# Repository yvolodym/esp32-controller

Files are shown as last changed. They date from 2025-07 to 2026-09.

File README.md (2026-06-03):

## Controller

ESP32-WROVER based wireless game controller. Two resistive (potentiometer)
analog joysticks plus an ST7789 SPI display, transmitting over ESP-NOW.
Firmware uses native ESP-IDF — see `CLAUDE.md` for architecture and pin
layout details.

### References

#### ESP-NOW
* https://randomnerdtutorials.com/esp32-cyd-esp-now-receive-data/
* https://habr.com/ru/companies/beget/articles/929336/
* https://wolles-elektronikkiste.de/esp-now
* https://github.com/SolderedElectronics/USB-UART-CH340C-converter-board-hardware-design

#### Joysticks (resistive thumbstick modules)
* https://tech.alpsalpine.com/e/products/detail/RKJXV122400R/
* https://github.com/dbenoy/thumbstick-breakout/blob/main/docs/board.png

#### LiPo charging module
* https://elektro.turanis.de/html/prj224/index.html

### Pin assignments

`CLAUDE.md` is the source of truth — the lists below are a quick reference.
All pins verified against `kicad/esp32-controller.kicad_sch` and
`kicad/supply.kicad_sch`.

#### ST7789 display (J1, 8-pin header — VSPI)

| J1 pin | Signal | GPIO |
|---|---|---|
| 1 | BL (backlight) | GPIO15 |
| 2 | CS  | GPIO5  |
| 3 | DC  | GPIO2  |
| 4 | RST | GPIO4  |
| 5 | MOSI / SDA | GPIO23 |
| 6 | SCK / SCL  | GPIO18 |
| 7 | VCC | +3.3 V |
| 8 | GND | GND |

#### Joystick 1 — RIGHT stick (U2 in schematic)

| Signal | GPIO | ADC |
|---|---|---|
| VRx (X axis) | GPIO32 | ADC1_CH4 |
| VRy (Y axis) | GPIO33 | ADC1_CH5 |
| Button (SEL) | GPIO25 | — *(not wired in hardware, see CLAUDE.md)* |

#### Joystick 2 — LEFT stick (U3 in schematic)

| Signal | GPIO | ADC |
|---|---|---|
| HRx (X axis) | GPIO34 | ADC1_CH6 |
| HRy (Y axis) | GPIO35 | ADC1_CH7 |
| Button (SEL) | GPIO26 | — *(not wired in hardware, see CLAUDE.md)* |

#### Battery sense

| Signal | GPIO | ADC |
|---|---|---|
| VBAT divider (R17 220 kΩ / R18 100 kΩ, net `HVBAT`) | GPIO36 (SENSOR_VP) | ADC1_CH0 |

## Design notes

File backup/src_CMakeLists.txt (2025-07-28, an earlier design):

idf_component_register(SRCS "main.cpp"
                    PRIV_INCLUDE_DIRS .
                    PRIV_REQUIRES nvs_flash
                    REQUIRES "fatfs" "esp_event" "esp_timer" "driver")
target_compile_definitions(${COMPONENT_LIB} PUBLIC "-DLOG_LOCAL_LEVEL=ESP_LOG_VERBOSE")

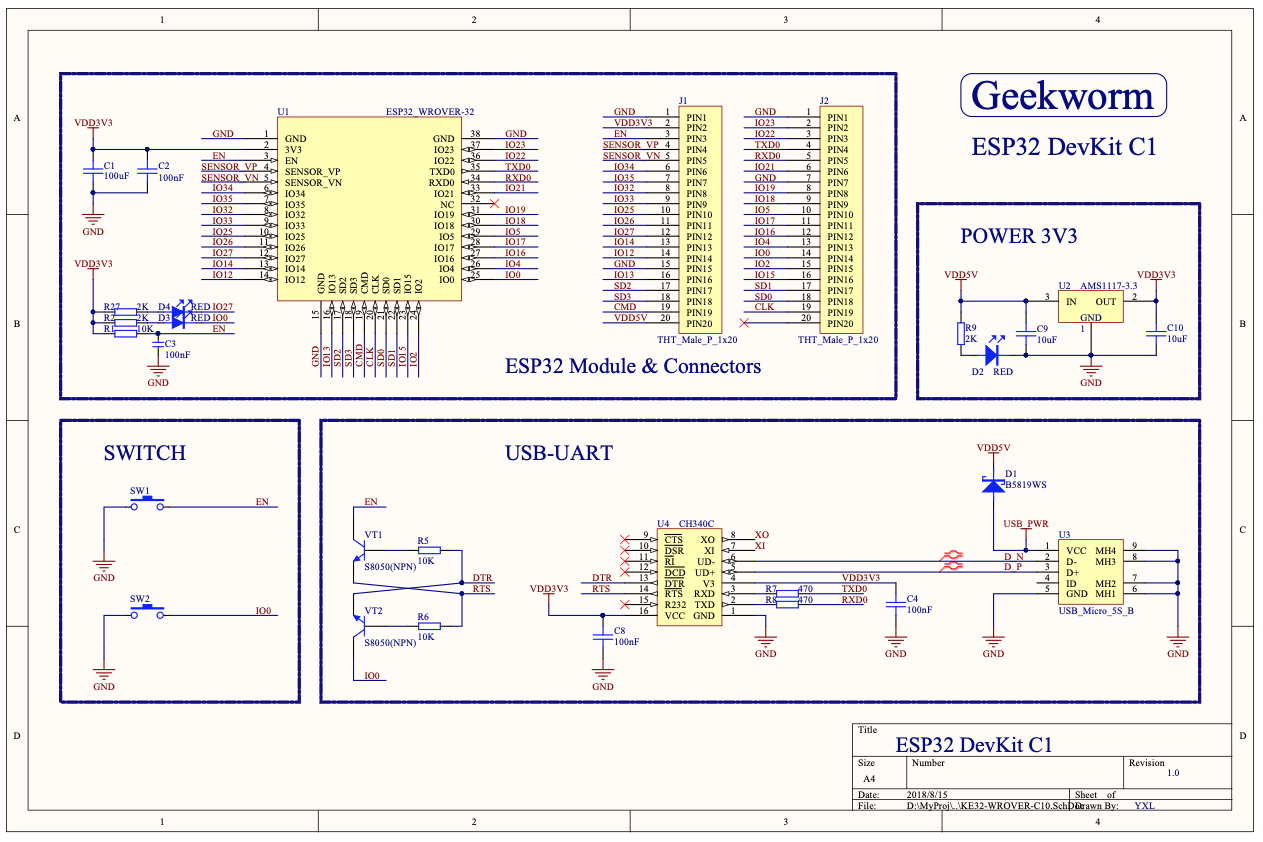
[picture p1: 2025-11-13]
doc/scematic.png

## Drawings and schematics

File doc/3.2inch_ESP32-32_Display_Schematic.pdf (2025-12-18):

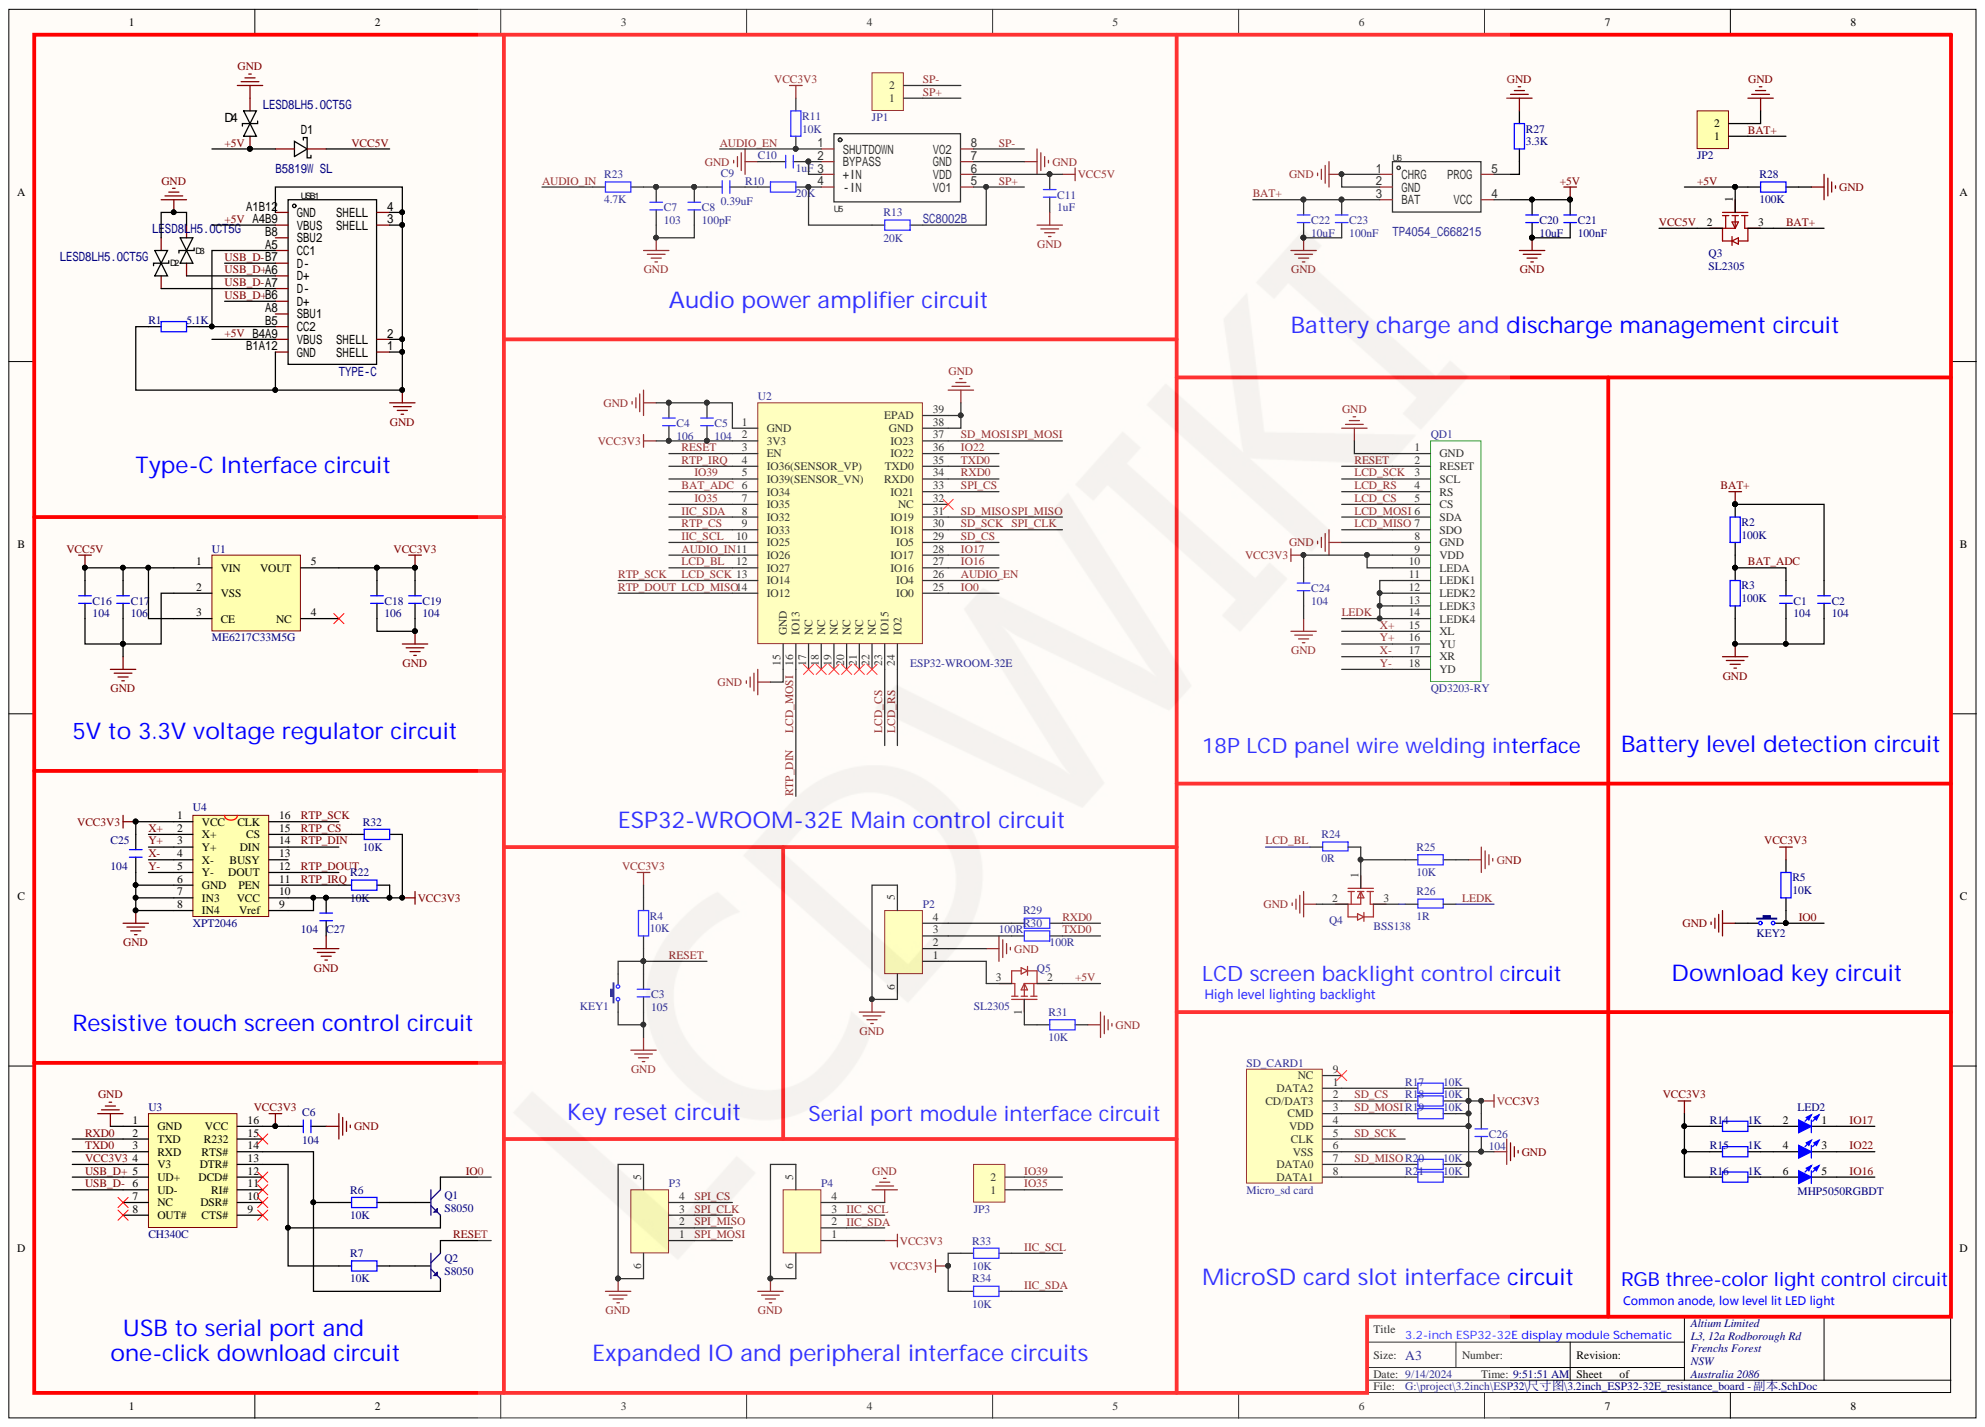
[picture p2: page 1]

GND
Audio power amplifier circuit

Battery charge and discharge management circuit

GND | BAT+

5V to 3.3V voltage regulator circuit

ESP32-WROOM-32E Main control circuit

High level lighting backlight

Resistive touch screen control circuit

R19 | | 10K | VCC3V3 SD_MOSI

VCC3V3 MHP5050RGBDT

Common anode, low level lit LED light

USB to serial port and
one-click download circuit

Expanded IO and peripheral interface circuits

Title 3.2-inch ESP32-32E display module Schematic | Altium Limited L3, 12a Rodborough Rd Frenchs Forest NSW Australia 2086

Size: A3 | Number: | Revision:

Date: 9/14/2024 Time: 9:51:51 AM | | Sheet of

G:\project\3.2inch\ESP32\尺寸图\3.2inch_ESP32-32E_resistance_board - 副本.SchDoc

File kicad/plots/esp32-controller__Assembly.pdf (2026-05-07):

1 | 2 | 3 | 4 | 5 | 6

A

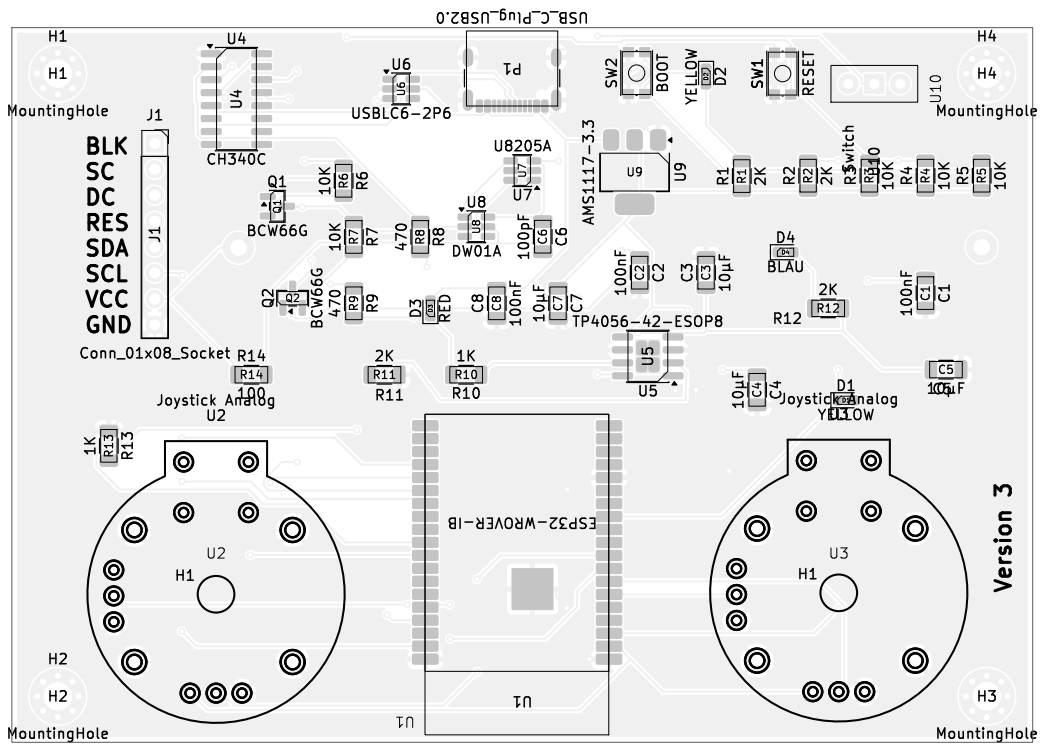
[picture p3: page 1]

1 | 2 | 3 | 4 | 5 | 6

A

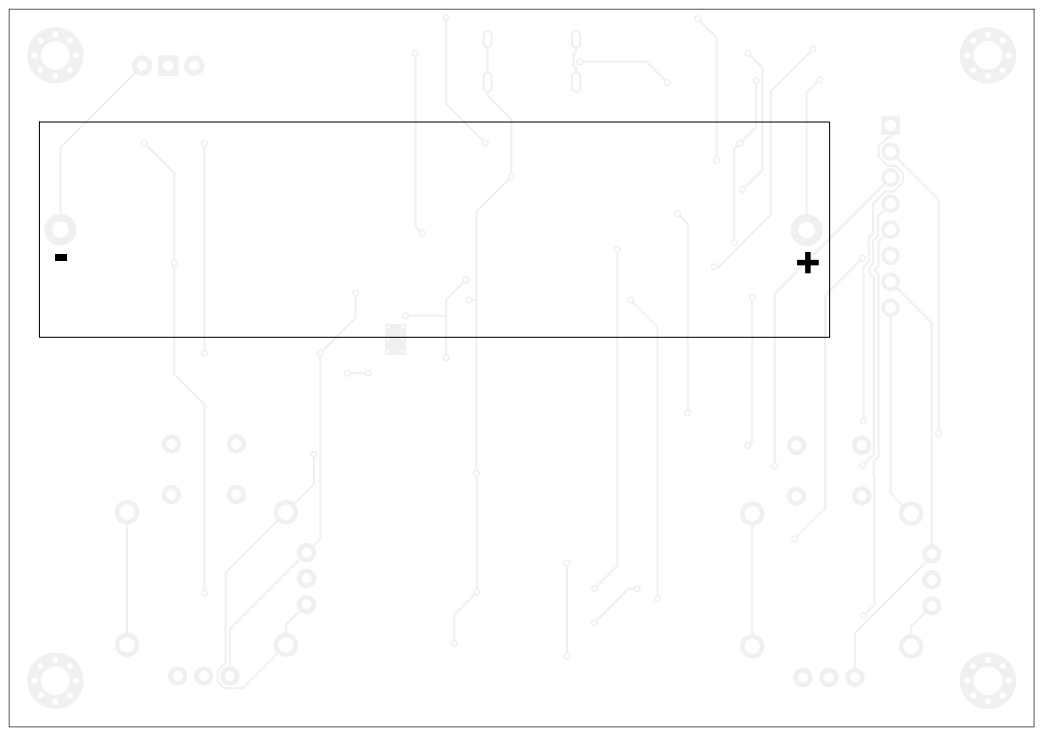
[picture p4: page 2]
D Date: KiCad; E.D.A. 9.0.8 Size: A4; Rev:; Id: /1 Title: File: esp32-controller.kicad_pcb Sheet: Black; And; White; BOT Board2Pdf:; Black; BOT -; Page 2/2

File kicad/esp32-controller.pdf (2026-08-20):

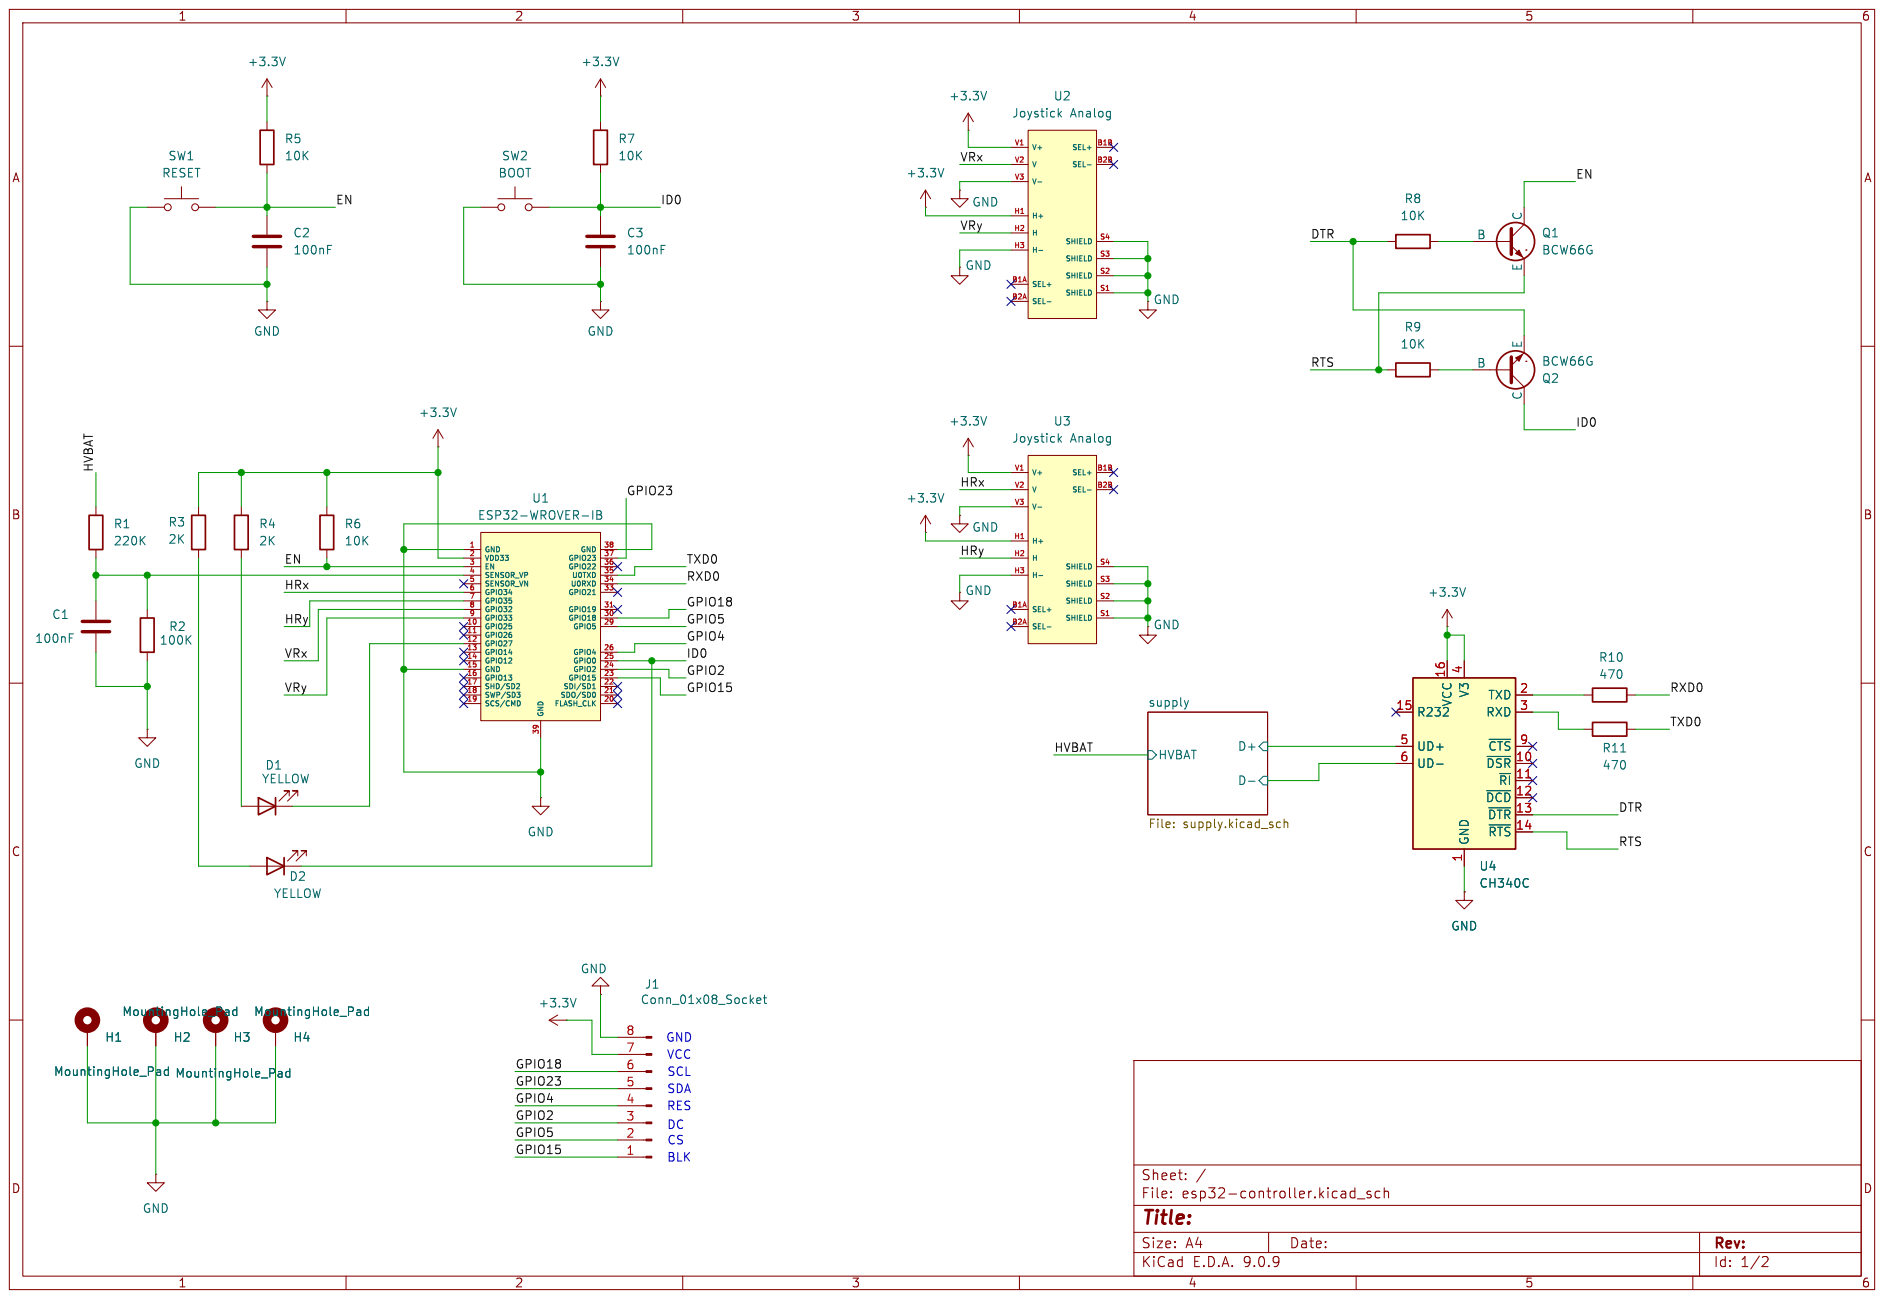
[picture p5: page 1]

VRy VRx HRx EN

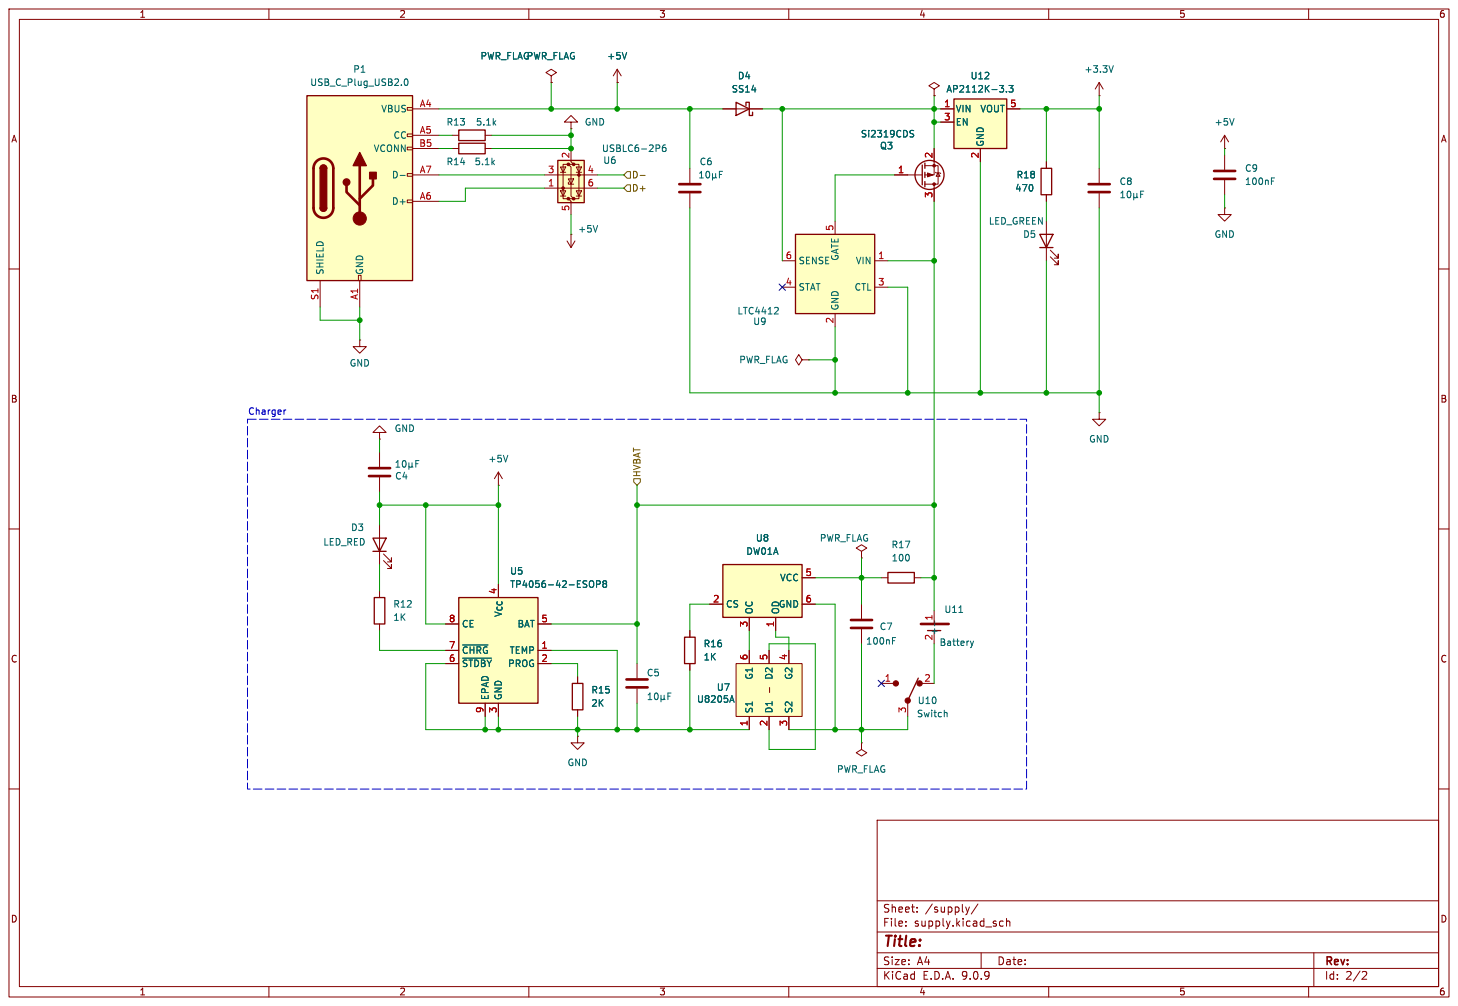
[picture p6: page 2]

3 CS 2 U5 TP4056-42-ESOP8 CE 8 ~{CHRG} 7 ~{STDBY} 6 EPAD

Id: 2/2 Title: File: supply.kicad_sch Sheet: /supply/ C5

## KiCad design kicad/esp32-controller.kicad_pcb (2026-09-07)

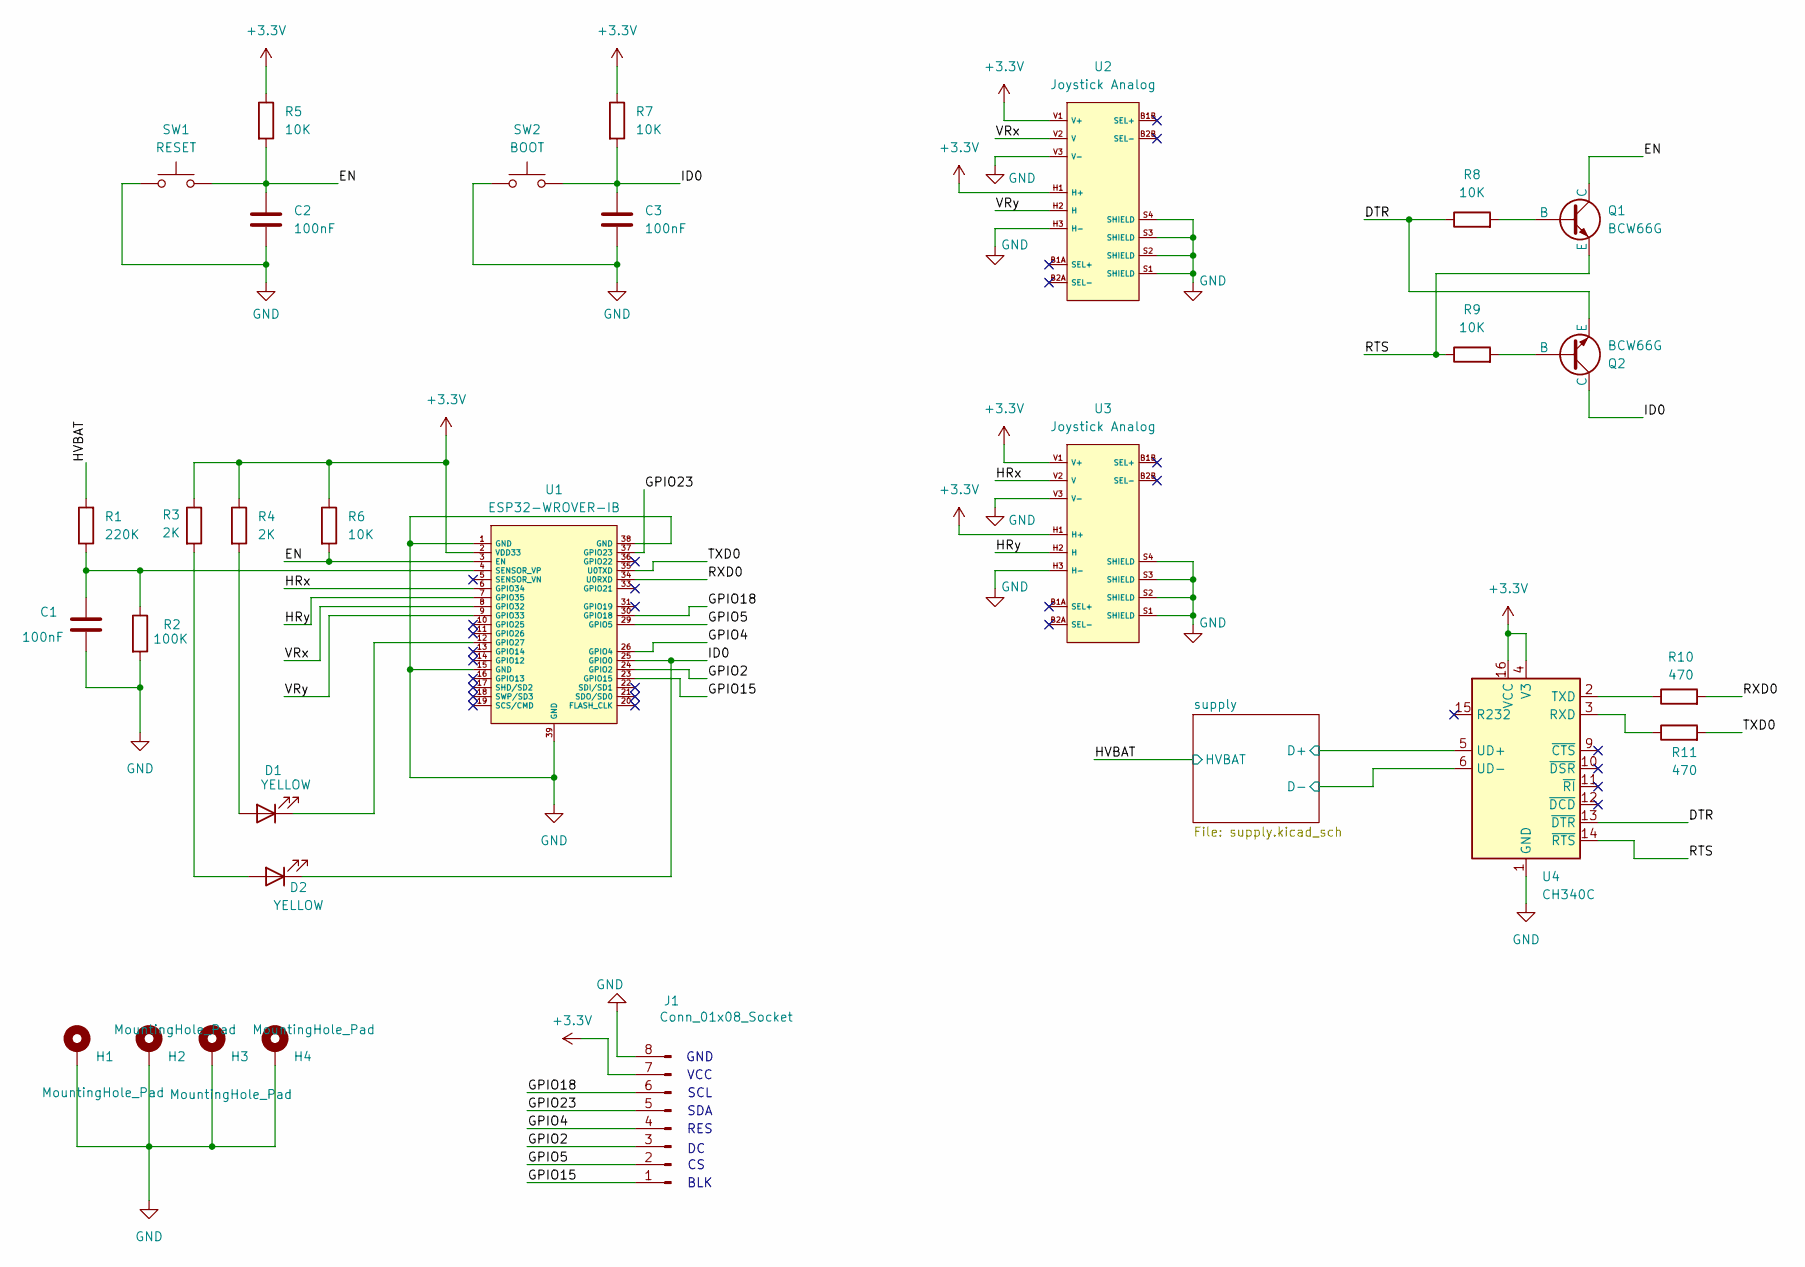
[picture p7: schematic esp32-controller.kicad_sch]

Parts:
C1, C2, C3: 100nF; C_1206_3216Metric
D1, D2: YELLOW; D_0603_1608Metric
H1, H2, H3, H4: MountingHole_Pad; MountingHole_2.7mm_Pad_Via
J1: Conn_01x08_Socket; PinSocket_1x08_P2.54mm_Vertical
Q1, Q2: BCW66G; SOT-23
R1: 220K; R_1206_3216Metric
R2: 100K; R_1206_3216Metric
R3, R4: 2K; R_1206_3216Metric
R5, R6, R7: 10K; R_1206_3216Metric
R8, R9: 10K; R_1206_3216Metric; LCSC C25819
R10, R11: 470; R_1206_3216Metric; LCSC C25819
SW1: RESET; SW_PUSH_1P1T_6x3.5mm_H4.3_APEM_MJTP1243
SW2: BOOT; SW_PUSH_1P1T_6x3.5mm_H4.3_APEM_MJTP1243
U1: ESP32-WROVER-IB
U2, U3: Joystick Analog; Joystick_Analog
U4: CH340C; SOIC-16_3.9x9.9mm_P1.27mm

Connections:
+3.3V: J1.7, R3.1, R4.1, R5.1, R6.1, R7.1, U1.2 (VDD33), U2.H1 (H+), U2.V1 (V+), U3.H1 (H+), U3.V1 (V+), U4.4 (V3), U4.16 (VCC); also elsewhere on the board
/DTR: Q2.3 (E), R8.1, U4.13 (~DTR)
/EN: C2.1, Q1.1 (C), R5.2, R6.2, SW1.2, U1.3 (EN)
/GPIO2: J1.3, U1.24 (GPIO2)
/GPIO4: J1.4, U1.26 (GPIO4)
/GPIO5: J1.2, U1.29 (GPIO5)
/GPIO15: J1.1, U1.23 (GPIO15)
/GPIO18: J1.6, U1.30 (GPIO18)
/GPIO23: J1.5, U1.37 (GPIO23)
/HRx: U1.6 (GPIO34), U3.V2 (V)
/HRy: U1.7 (GPIO35), U3.H2 (H)
/HVBAT: R1.2; also elsewhere on the board
/ID0: C3.1, D2.1 (K), Q2.1 (C), R7.2, SW2.2, U1.25 (GPIO0)
/RTS: Q1.3 (E), R9.1, U4.14 (~RTS)
/RXD0: R10.2, U1.34 (U0RXD)
/TXD0: R11.2, U1.35 (U0TXD)
/VRx: U1.8 (GPIO32), U2.V2 (V)
/VRy: U1.9 (GPIO33), U2.H2 (H)
/supply/D+: U4.5 (UD+); also elsewhere on the board
/supply/D-: U4.6 (UD-); also elsewhere on the board
GND: C1.2, C2.2, C3.2, H1.1, H2.1, H3.1, H4.1, J1.8, R2.2, SW1.1, SW2.1, U1.1 (GND), U1.15 (GND), U1.38 (GND), U1.39 (GND), U2.H3 (H-), U2.S1 (SHIELD), U2.S2 (SHIELD), U2.S3 (SHIELD), U2.S4 (SHIELD), U2.V3 (V-), U3.H3 (H-), U3.S1 (SHIELD), U3.S2 (SHIELD), U3.S3 (SHIELD), U3.S4 (SHIELD), U3.V3 (V-), U4.1 (GND); also elsewhere on the board
unnamed: D1.2 (A), R4.2
unnamed: D1.1 (K), U1.12 (GPIO27)
unnamed: D2.2 (A), R3.2
unnamed: Q1.2 (B), R8.2
unnamed: Q2.2 (B), R9.2
unnamed: C1.1, R1.1, R2.1, U1.4 (SENSOR_VP)
unnamed: R11.1, U4.3 (RXD)
unnamed: R10.1, U4.2 (TXD)

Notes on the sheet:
RES
VCC
SCL
GND
BLK
SDA

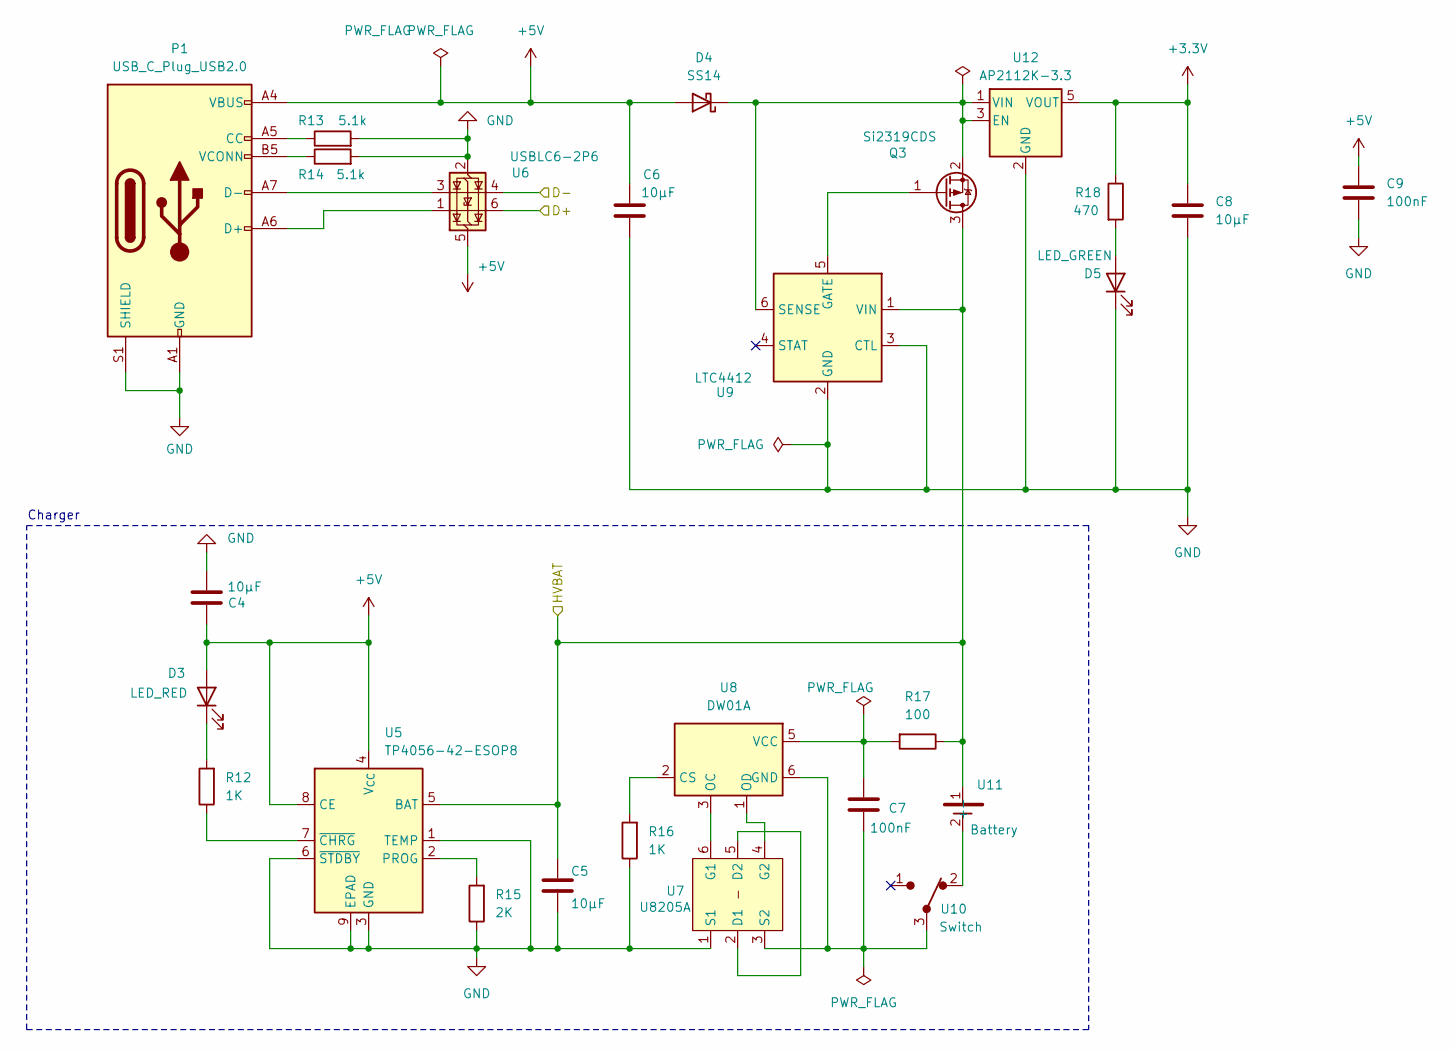
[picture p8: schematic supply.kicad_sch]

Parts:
C4, C5, C6, C8: 10µF; C_1206_3216Metric
C7, C9: 100nF; C_1206_3216Metric
D3: LED_RED; LED_D2.0mm_W4.8mm_H2.5mm_FlatTop
D4: SS14; D_SMA
D5: LED_GREEN; LED_D2.0mm_W4.8mm_H2.5mm_FlatTop
P1: USB_C_Plug_USB2.0; USB_C_Receptacle_GCT_USB4105-xx-A_16P_TopMnt_Horizontal; LCSC C456012
Q3: Si2319CDS; SOT-23
R12, R16: 1K; R_1206_3216Metric
R13, R14: 5.1k; R_1206_3216Metric
R15: 2K; R_1206_3216Metric
R17: 100; R_1206_3216Metric
R18: 470; R_1206_3216Metric
U5: TP4056-42-ESOP8; SOIC-8-1EP_3.9x4.9mm_P1.27mm_EP2.41x3.3mm_ThermalVias
U6: USBLC6-2P6; SOT-23-6
U7: U8205A; SOT-23-6
U8: DW01A; SOT-23-6
U9: LTC4412; TSOT-23-6
U10: Switch; SW_SPDT_PCM12
U11: Battery; NCR18650B
U12: AP2112K-3.3; SOT-23-5

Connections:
+3.3V: C8.1, R18.1, U12.5 (VOUT); also elsewhere on the board
+5V: C4.1, C6.1, C9.2, D3.2 (A), D4.2 (A), P1.A4 (VBUS), P1.A9 (VBUS), P1.B4 (VBUS), P1.B9 (VBUS), U5.4 (V_{CC}), U5.8 (CE), U6.5 (VBUS)
/HVBAT: C5.1, Q3.3 (D), R17.1, U5.5 (BAT), U9.1 (VIN), U11.1 (+); also elsewhere on the board
/supply/D+: U6.6 (I/O1); also elsewhere on the board
/supply/D-: U6.4 (I/O2); also elsewhere on the board
GND: C4.2, C5.2, C6.2, C8.2, C9.1, D5.1 (K), P1.A1 (GND), P1.A12 (GND), P1.B1 (GND), P1.B12 (GND), P1.S1 (SHIELD), R13.2, R14.2, R15.1, R16.1, U5.1 (TEMP), U5.3 (GND), U5.6 (~STDBY), U5.9 (EPAD), U6.2 (GND), U7.1 (S1), U9.2 (GND), U9.3 (CTL), U12.2 (GND); also elsewhere on the board
unnamed: D3.1 (K), R12.2
unnamed: D4.1 (K), Q3.2 (S), U9.6 (SENSE), U12.1 (VIN), U12.3 (EN)
unnamed: D5.2 (A), R18.2
unnamed: P1.A5 (CC), R13.1
unnamed: P1.A6 (D+), U6.1 (I/O1)
unnamed: P1.A7 (D-), U6.3 (I/O2)
unnamed: P1.B5 (VCONN), R14.1
unnamed: Q3.1 (G), U9.5 (GATE)
unnamed: R15.2, U5.2 (PROG)
unnamed: R12.1, U5.7 (~CHRG)
unnamed: U7.2 (D1), U7.5 (D2)
unnamed: U7.6 (G1), U8.3 (OC)
unnamed: U7.4 (G2), U8.1 (OD)
unnamed: C7.1, U7.3 (S2), U8.6 (GND), U10.3
unnamed: R16.2, U8.2 (CS)
unnamed: C7.2, R17.2, U8.5 (VCC)
unnamed: U10.2, U11.2 (-)

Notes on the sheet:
Charger

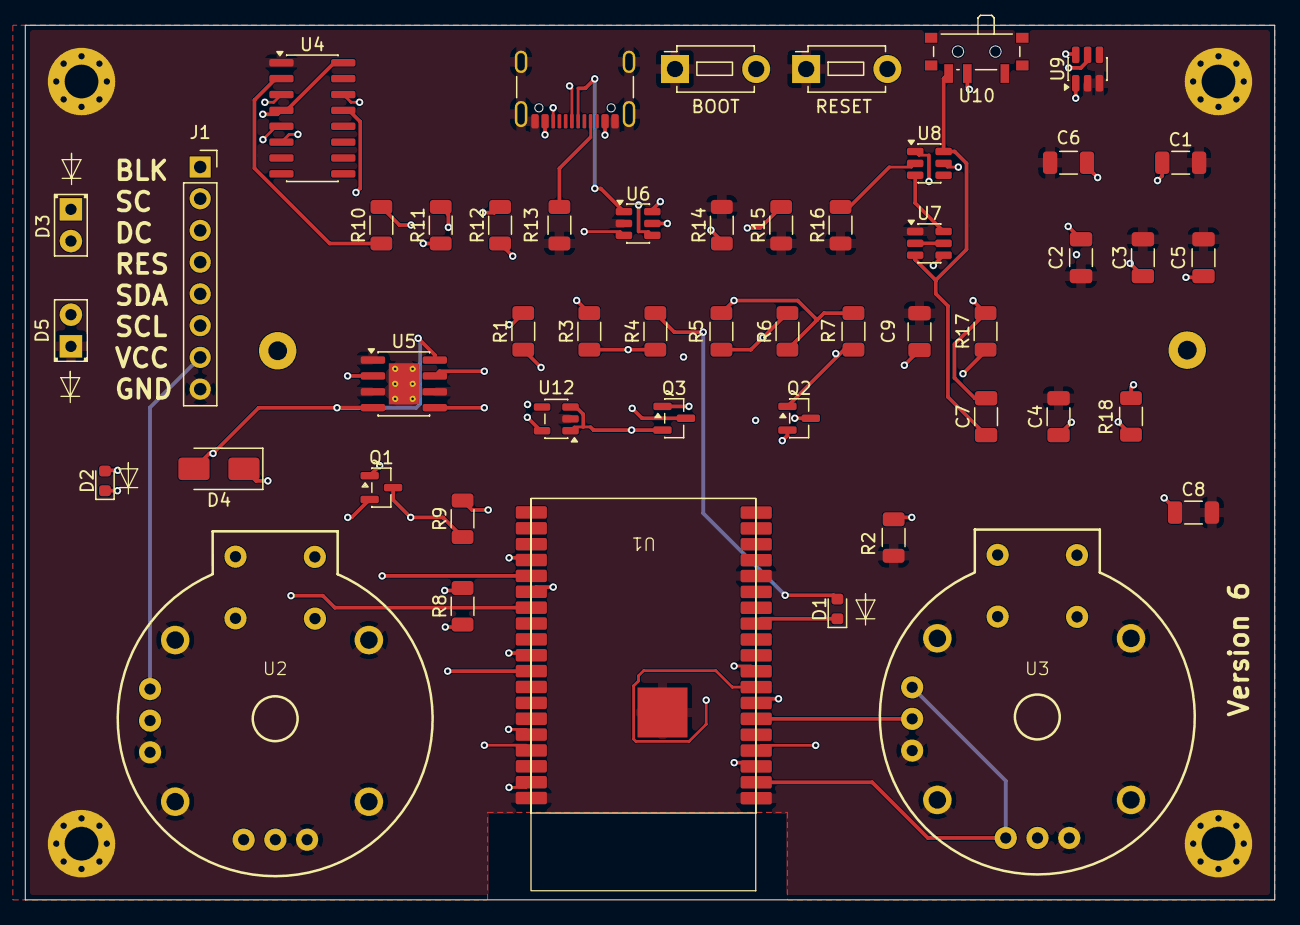
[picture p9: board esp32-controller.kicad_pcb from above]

Board: 4 copper layers, 100.0 x 70.0 mm, 55 parts (1 on the bottom side), 47 nets.

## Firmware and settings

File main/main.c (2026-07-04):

#include <stdio.h>
#include <string.h>
#include <stdlib.h>
#include <freertos/FreeRTOS.h>
#include <freertos/task.h>
#include <esp_system.h>
#include <esp_wifi.h>
#include <esp_now.h>
#include <esp_log.h>
#include <esp_adc/adc_oneshot.h>
#include <esp_adc/adc_cali.h>
#include <esp_adc/adc_cali_scheme.h>
#include <driver/gpio.h>
#include <nvs_flash.h>
#include <sdkconfig.h>
#include "st7789_display.h"

static const char *TAG = "ESP32_CONTROLLER";

// ========== CONFIGURATION ========== //
// Joystick 1 (U2 in schematic, net /VRx /VRy)
#define JOY1_X_PIN ADC_CHANNEL_4  // GPIO32 - X-axis joystick 1
#define JOY1_Y_PIN ADC_CHANNEL_5  // GPIO33 - Y-axis joystick 1
// Joystick 2 (U3 in schematic, net /HRx /HRy)
#define JOY2_X_PIN ADC_CHANNEL_6  // GPIO34 - X-axis joystick 2
#define JOY2_Y_PIN ADC_CHANNEL_7  // GPIO35 - Y-axis joystick 2
// Joystick buttons
#define JOY1_BTN_PIN GPIO_NUM_25  // Joystick 1 button
#define JOY2_BTN_PIN GPIO_NUM_26  // Joystick 2 button

// Battery voltage sense — VBAT through a 220k/100k divider into GPIO36.
// HW prerequisite: R17/R18/C9 (net VBAT_SENSE) on supply.kicad_sch.
// The divider taps HVBAT = the raw 18650 + terminal (verified against the
// netlist: net /HVBAT = U10.1 / U5.BAT / U12.VIN / D6.anode). D6 and Q3 are
// downstream of the tap, so this reads true battery voltage, not the VPWR rail.
#define BATT_SENSE_PIN   ADC_CHANNEL_0  // GPIO36 (SENSOR_VP) - VBAT divider tap
#define BATT_DIVIDER_NUM 320            // 220k + 100k
#define BATT_DIVIDER_DEN 100            // 100k
// EMA smoothing across calls: tau ~= SEND_DELAY_MS * 2^SHIFT. At 20 ms/call,
// SHIFT=6 -> ~1.3 s, enough to ride out boot / WiFi-TX current spikes.
#define BATT_EMA_SHIFT   6

const uint32_t SEND_DELAY_MS = CONFIG_CONTROLLER_SEND_DELAY_MS; // Delay between transmissions (ms)
const int DEADZONE = CONFIG_CONTROLLER_JOYSTICK_DEADZONE;      // Joystick deadzone

typedef struct {
    int16_t joy1_x;
    int16_t joy1_y;
    int16_t joy2_x;
    int16_t joy2_y;
    bool joy1_btn;
    bool joy2_btn;
    uint8_t batteryLevel;
} ControllerData;

static ControllerData txData;
// Receiver MAC address from configuration
static uint8_t receiverMac[6];

// ADC handles
static adc_oneshot_unit_handle_t adc1_handle;
static adc_cali_handle_t adc1_cali_handle = NULL;
static bool adc_calibrated = false;

// Per-axis center reference (set by calibrate_joystick_centers at boot).
// Order: J1_X, J1_Y, J2_X, J2_Y. Stored in the same coordinate space as
// the post-voltage-calibration ADC value used in calibrateJoystick().
static int joy_centers[4] = {2048, 2048, 2048, 2048};

// Display handle
static st7789_display_t display = {0};

// Transmission statistics
static uint32_t send_success_count = 0;
static uint32_t send_fail_count = 0;

// Parse MAC address from configuration string
static void parse_mac_address(void) {
    const char* mac_str = CONFIG_CONTROLLER_RECEIVER_MAC;
    sscanf(mac_str, "%hhx:%hhx:%hhx:%hhx:%hhx:%hhx",
           &receiverMac[0], &receiverMac[1], &receiverMac[2],
           &receiverMac[3], &receiverMac[4], &receiverMac[5]);
    ESP_LOGI(TAG, "Receiver MAC: %02x:%02x:%02x:%02x:%02x:%02x",
             receiverMac[0], receiverMac[1], receiverMac[2],
             receiverMac[3], receiverMac[4], receiverMac[5]);
}

// ESP-NOW Send Callback
static void espnow_send_cb(const wifi_tx_info_t *tx_info, esp_now_send_status_t status) {
    if (status == ESP_NOW_SEND_SUCCESS) {
        send_success_count++;
    } else {
        send_fail_count++;
        ESP_LOGW(TAG, "Send failed, count: %lu", send_fail_count);
    }
}

// Convert raw ADC reading to voltage-calibrated equivalent (0..4095 space).
static int adc_to_calibrated(int rawValue) {
    if (adc_calibrated && adc1_cali_handle != NULL) {
        int voltage = rawValue;
        adc_cali_raw_to_voltage(adc1_cali_handle, rawValue, &voltage);
        return (voltage * 4095) / 3300;
    }
    return rawValue;
}

// Joystick calibration — uses per-axis center captured at boot.
static int16_t calibrateJoystick(int rawValue, int center) {
    int v = adc_to_calibrated(rawValue);
    int16_t mapped = (int16_t)((v - center) * 512 / 2048);
    if (abs(mapped) < DEADZONE) return 0;
    return mapped;
}

// Sample all 4 axes with sticks at rest and store the average as the zero reference.
static void calibrate_joystick_centers(void) {
    const int SAMPLES = 32;
    const adc_channel_t channels[4] = {JOY1_X_PIN, JOY1_Y_PIN, JOY2_X_PIN, JOY2_Y_PIN};
    int sums[4] = {0};
    for (int s = 0; s < SAMPLES; s++) {
        for (int i = 0; i < 4; i++) {
            int raw;
            ESP_ERROR_CHECK(adc_oneshot_read(adc1_handle, channels[i], &raw));
            sums[i] += adc_to_calibrated(raw);
        }
        vTaskDelay(pdMS_TO_TICKS(5));
    }
    for (int i = 0; i < 4; i++) {
        joy_centers[i] = sums[i] / SAMPLES;
    }
    ESP_LOGI(TAG, "Joystick centers: J1=(%d,%d) J2=(%d,%d)",
             joy_centers[0], joy_centers[1], joy_centers[2], joy_centers[3]);
}

// GPIO initialization for buttons
static void init_gpio(void) {
    gpio_config_t io_conf = {
        .intr_type = GPIO_INTR_DISABLE,
        .mode = GPIO_MODE_INPUT,
        .pin_bit_mask = (1ULL << JOY1_BTN_PIN) | (1ULL << JOY2_BTN_PIN),
        .pull_down_en = 0,
        .pull_up_en = 1,
    };
    gpio_config(&io_conf);
}

// ADC initialization
static void init_adc(void) {
    adc_oneshot_unit_init_cfg_t init_config1 = {
        .unit_id = ADC_UNIT_1,
        .ulp_mode = ADC_ULP_MODE_DISABLE,
    };
    ESP_ERROR_CHECK(adc_oneshot_new_unit(&init_config1, &adc1_handle));

    adc_oneshot_chan_cfg_t config = {
        .bitwidth = ADC_BITWIDTH_12,
        .atten = ADC_ATTEN_DB_12,
    };

    ESP_ERROR_CHECK(adc_oneshot_config_channel(adc1_handle, JOY1_X_PIN, &config));
    ESP_ERROR_CHECK(adc_oneshot_config_channel(adc1_handle, JOY1_Y_PIN, &config));
    ESP_ERROR_CHECK(adc_oneshot_config_channel(adc1_handle, JOY2_X_PIN, &config));
    ESP_ERROR_CHECK(adc_oneshot_config_channel(adc1_handle, JOY2_Y_PIN, &config));
    ESP_ERROR_CHECK(adc_oneshot_config_channel(adc1_handle, BATT_SENSE_PIN, &config));

    // Initialize ADC calibration
#if ADC_CALI_SCHEME_CURVE_FITTING_SUPPORTED
    adc_cali_curve_fitting_config_t cali_config = {
        .unit_id = ADC_UNIT_1,
        .atten = ADC_ATTEN_DB_12,
        .bitwidth = ADC_BITWIDTH_12,
    };
    esp_err_t ret = adc_cali_create_scheme_curve_fitting(&cali_config, &adc1_cali_handle);
    if (ret == ESP_OK) {
        adc_calibrated = true;
        ESP_LOGI(TAG, "ADC calibration enabled (Curve Fitting)");
    }
#elif ADC_CALI_SCHEME_LINE_FITTING_SUPPORTED
    adc_cali_line_fitting_config_t cali_config = {
        .unit_id = ADC_UNIT_1,
        .atten = ADC_ATTEN_DB_12,
        .bitwidth = ADC_BITWIDTH_12,
    };
    esp_err_t ret = adc_cali_create_scheme_line_fitting(&cali_config, &adc1_cali_handle);
    if (ret == ESP_OK) {
        adc_calibrated = true;
        ESP_LOGI(TAG, "ADC calibration enabled (Line Fitting)");
    }
#endif
    if (!adc_calibrated) {
        ESP_LOGW(TAG, "ADC calibration not available - using raw values");
    }
}

// WiFi and ESP-NOW initialization
static void init_wifi_espnow(void) {
    ESP_ERROR_CHECK(esp_netif_init());
    ESP_ERROR_CHECK(esp_event_loop_create_default());
    wifi_init_config_t cfg = WIFI_INIT_CONFIG_DEFAULT();
    ESP_ERROR_CHECK(esp_wifi_init(&cfg));
    ESP_ERROR_CHECK(esp_wifi_set_storage(WIFI_STORAGE_RAM));
    ESP_ERROR_CHECK(esp_wifi_set_mode(WIFI_MODE_STA));
    ESP_ERROR_CHECK(esp_wifi_start());

    // Parse MAC address from configuration
    parse_mac_address();

    ESP_ERROR_CHECK(esp_now_init());

    // Register callback for send confirmation
    ESP_ERROR_CHECK(esp_now_register_send_cb(espnow_send_cb));

    esp_now_peer_info_t peerInfo = {0};
    memcpy(peerInfo.peer_addr, receiverMac, 6);
    peerInfo.channel = 1;
    peerInfo.encrypt = false;
    peerInfo.ifidx = WIFI_IF_STA;

    ESP_ERROR_CHECK(esp_now_add_peer(&peerInfo));
    ESP_LOGI(TAG, "ESP-NOW initialized and peer added");
}

// LiPo open-circuit-voltage -> state-of-charge curve. LiPo discharge is
// strongly non-linear, so the old linear 3.0-4.2 V map badly mis-reported the
// mid-range. Points are descending in voltage; values between are interpolated.
static const struct { int mv; int pct; } BATT_CURVE[] = {
    { 4200, 100 },
    { 4000,  85 },
    { 3800,  60 },
    { 3700,  40 },
    { 3600,  20 },
    { 3300,   5 },
    { 3000,   0 },
};

static uint8_t vbat_mv_to_percent(int mv) {
    const int n = sizeof(BATT_CURVE) / sizeof(BATT_CURVE[0]);
    if (mv >= BATT_CURVE[0].mv)     return 100;
    if (mv <= BATT_CURVE[n - 1].mv) return 0;
    for (int i = 0; i < n - 1; i++) {
        int hi_mv = BATT_CURVE[i].mv,     hi_pct = BATT_CURVE[i].pct;
        int lo_mv = BATT_CURVE[i + 1].mv, lo_pct = BATT_CURVE[i + 1].pct;
        if (mv <= hi_mv && mv >= lo_mv) {
            return (uint8_t)(lo_pct + (mv - lo_mv) * (hi_pct - lo_pct) / (hi_mv - lo_mv));
        }
    }
    return 0;
}

// Running EMA of the recovered VBAT (mV); -1 until seeded by the first read.
static int batt_ema_mv = -1;

// Read VBAT through the resistor divider and map to a 0..100% LiPo estimate.
// Reuses the joystick ADC calibration (same unit/atten/bitwidth). The 100nF on
// the divider keeps the tap stable within a call; the EMA below smooths across
// calls so transient load (boot, WiFi TX) doesn't swing the reported level.
static uint8_t read_battery_level(void) {
    const int SAMPLES = 32;
    int raw_sum = 0;
    for (int i = 0; i < SAMPLES; i++) {
        int raw;
        if (adc_oneshot_read(adc1_handle, BATT_SENSE_PIN, &raw) == ESP_OK) {
            raw_sum += raw;
        }
    }
    int raw_avg = raw_sum / SAMPLES;

    // Voltage at the ADC pin (mV).
    int pin_mv;
    if (adc_calibrated && adc1_cali_handle != NULL) {
        adc_cali_raw_to_voltage(adc1_cali_handle, raw_avg, &pin_mv);
    } else {
        pin_mv = raw_avg * 3300 / 4095;  // crude fallback without calibration
    }

    // Undo the divider to recover VBAT, then smooth over time.
    int vbat_mv = pin_mv * BATT_DIVIDER_NUM / BATT_DIVIDER_DEN;
    if (batt_ema_mv < 0) {
        batt_ema_mv = vbat_mv;  // seed on first call
    } else {
        batt_ema_mv += (vbat_mv - batt_ema_mv) >> BATT_EMA_SHIFT;
    }

    return vbat_mv_to_percent(batt_ema_mv);
}

// Pre-charge the divider filter and converge the EMA before the main loop, so
// the first reported level reflects a settled VBAT rather than the boot-time
// current spike (which otherwise reads low and "climbs" over the first seconds
// as the supply settles). Runs after the ~2 s ready screen, i.e. well past the
// WiFi/display init surge.
static void battery_sense_seed(void) {
    for (int i = 0; i < 16; i++) {
        read_battery_level();
        vTaskDelay(pdMS_TO_TICKS(20));
    }
}

// Data transmission
static void send_data(void) {
    int raw_value;

    // Read joysticks
    ESP_ERROR_CHECK(adc_oneshot_read(adc1_handle, JOY1_X_PIN, &raw_value));
    txData.joy1_x = calibrateJoystick(raw_value, joy_centers[0]);

    ESP_ERROR_CHECK(adc_oneshot_read(adc1_handle, JOY1_Y_PIN, &raw_value));
    txData.joy1_y = calibrateJoystick(raw_value, joy_centers[1]);

    ESP_ERROR_CHECK(adc_oneshot_read(adc1_handle, JOY2_X_PIN, &raw_value));
    txData.joy2_x = calibrateJoystick(raw_value, joy_centers[2]);

    ESP_ERROR_CHECK(adc_oneshot_read(adc1_handle, JOY2_Y_PIN, &raw_value));
    txData.joy2_y = calibrateJoystick(raw_value, joy_centers[3]);

    // Read buttons (invert due to PULLUP)
    txData.joy1_btn = !gpio_get_level(JOY1_BTN_PIN);
    txData.joy2_btn = !gpio_get_level(JOY2_BTN_PIN);

    // Battery level from the VBAT divider on GPIO36 (see read_battery_level):
    // EMA-smoothed VBAT mapped through the non-linear LiPo curve. Requires
    // R17/R18/C9 (net VBAT_SENSE) populated on supply.kicad_sch; without the
    // divider GPIO36 floats and the reading is meaningless.
    txData.batteryLevel = read_battery_level();

    // Send data
    esp_err_t result = esp_now_send(receiverMac, (uint8_t *)&txData, sizeof(txData));

    // Debug information (every 100 transmissions)
    static uint32_t debug_counter = 0;
    debug_counter++;
    if (debug_counter % 100 == 0 || result != ESP_OK) {
        ESP_LOGI(TAG, "J1: %d,%d BTN:%d | J2: %d,%d BTN:%d | Battery: %d%% | Send: %lu/%lu | Status: %s",
            txData.joy1_x, txData.joy1_y, txData.joy1_btn,
            txData.joy2_x, txData.joy2_y, txData.joy2_btn,
            txData.batteryLevel,
            send_success_count, send_fail_count,
            result == ESP_OK ? "OK" : "FAIL");
    }
}

// Main controller task
static void controller_task(void *pvParameters) {
    ESP_LOGI(TAG, "Controller ready to work");

    // Seed the battery EMA on settled VBAT before the loop so the first
    // reported level doesn't reflect the boot current spike.
    battery_sense_seed();

    uint32_t display_update_counter = 0;

    while (1) {
        send_data();

        // Update display every 10th cycle (200ms with 20ms delay)
        display_update_counter++;
        if (display_update_counter >= 10) {
            display_update_counter = 0;
            if (display.initialized) {
                st7789_display_joystick_data(&display,
                    txData.joy1_x, txData.joy1_y,
                    txData.joy2_x, txData.joy2_y,
                    txData.joy1_btn, txData.joy2_btn,
                    txData.batteryLevel);
            }
        }

        vTaskDelay(pdMS_TO_TICKS(SEND_DELAY_MS));
    }
}

void app_main(void) {
    ESP_LOGI(TAG, "Starting ESP32 controller");

    // Initialize NVS Flash (for WiFi)
    esp_err_t ret = nvs_flash_init();
    if (ret == ESP_ERR_NVS_NO_FREE_PAGES || ret == ESP_ERR_NVS_NEW_VERSION_FOUND) {
        ESP_ERROR_CHECK(nvs_flash_erase());
        ret = nvs_flash_init();
    }
    ESP_ERROR_CHECK(ret);

    // Initialize display first
    ESP_LOGI(TAG, "Initializing ST7789 display...");
    ret = st7789_init(&display);
    if (ret == ESP_OK) {
        // Display 320x170 — two centered lines at FONT_SCALE=2 (16x16 px chars).
        // Vertical center of two 16 px lines + 10 px gap = (170-42)/2 = 64.
        st7789_fill_screen(&display, ST7789_BLACK);
        st7789_draw_string_centered(&display, 64, "ESP32 CONTROLLER", ST7789_CYAN, ST7789_BLACK, FONT_SCALE);
        st7789_draw_string_centered(&display, 90, "INITIALIZING...", ST7789_WHITE, ST7789_BLACK, FONT_SCALE);

        ESP_LOGI(TAG, "Display initialized and welcome message shown");
    } else {
        ESP_LOGE(TAG, "Display initialization failed: %s", esp_err_to_name(ret));
    }

    // Initialize components
    init_gpio();
    init_adc();
    calibrate_joystick_centers();
    init_wifi_espnow();

    // Update display: System ready
    if (display.initialized) {
        st7789_fill_screen(&display, ST7789_BLACK);
        st7789_draw_string_centered(&display, 64, "ESP32 CONTROLLER", ST7789_GREEN, ST7789_BLACK, FONT_SCALE);
        st7789_draw_string_centered(&display, 90, "SYSTEM READY!", ST7789_YELLOW, ST7789_BLACK, FONT_SCALE);
    }

    // Short delay for stabilization
    vTaskDelay(pdMS_TO_TICKS(2000));

    // Clear screen for data display
    if (display.initialized) {
        st7789_fill_screen(&display, ST7789_BLACK);
    }

    // Create main task
    xTaskCreate(controller_task, "controller_task", 8192, NULL, 5, NULL);
}

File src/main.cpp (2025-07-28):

#include <Arduino.h>
#include <WiFi.h>
#include <esp_now.h>

// ========== НАСТРОЙКИ ========== //
// Джойстик 1
#define JOY1_X_PIN 32  // X-ось джойстика 1
#define JOY1_Y_PIN 33  // Y-ось джойстика 1
// Джойстик 2
#define JOY2_X_PIN 34  // X-ось джойстика 2
#define JOY2_Y_PIN 35  // Y-ось джойстика 2
// Кнопки джойстиков
#define JOY1_BTN_PIN 12  // Кнопка джойстика 1
#define JOY2_BTN_PIN 14  // Кнопка джойстика 2

const uint32_t SEND_DELAY = 20; // Задержка между отправками (мс)
const int DEADZONE = 50;  // Мертвая зона джойстика

typedef struct {
  int16_t joy1_x;
  int16_t joy1_y;
  int16_t joy2_x;
  int16_t joy2_y;
  bool joy1_btn;
  bool joy2_btn;
  uint8_t batteryLevel;
} ControllerData;

ControllerData txData;
// Замените на MAC-адрес вашего приёмника
uint8_t receiverMac[] = {0x94, 0x3C, 0xC6, 0x33, 0x71, 0x68};

// Калибровка джойстика
int16_t calibrateJoystick(int rawValue) {
  int16_t mapped = map(rawValue, 0, 4095, -512, 512);
  if (abs(mapped) < DEADZONE) return 0;
  return mapped;
}

void setup() {
  Serial.begin(115200);
  delay(100);
  
  // Настройка пинов
  pinMode(JOY1_BTN_PIN, INPUT_PULLUP);
  pinMode(JOY2_BTN_PIN, INPUT_PULLUP);

  // Инициализация WiFi
  WiFi.mode(WIFI_STA);
  WiFi.disconnect();
  delay(100);

  if (esp_now_init() != ESP_OK) {
    Serial.println("Ошибка инициализации ESP-NOW");
    ESP.restart();
  }

  esp_now_peer_info_t peerInfo;
  memset(&peerInfo, 0, sizeof(peerInfo));
  memcpy(peerInfo.peer_addr, receiverMac, 6);
  peerInfo.channel = 1;
  peerInfo.encrypt = false;
  
  if (esp_now_add_peer(&peerInfo) != ESP_OK) {
    Serial.println("Ошибка добавления получателя");
    ESP.restart();
  }

  Serial.println("Контроллер готов к работе");
}

void sendData() {
  // Чтение джойстиков
  txData.joy1_x = calibrateJoystick(analogRead(JOY1_X_PIN));
  txData.joy1_y = calibrateJoystick(analogRead(JOY1_Y_PIN));
  txData.joy2_x = calibrateJoystick(analogRead(JOY2_X_PIN));
  txData.joy2_y = calibrateJoystick(analogRead(JOY2_Y_PIN));
  
  // Чтение кнопок (инвертируем из-за PULLUP)
  txData.joy1_btn = !digitalRead(JOY1_BTN_PIN);
  txData.joy2_btn = !digitalRead(JOY2_BTN_PIN);
  
  // Чтение батареи (опционально)
  txData.batteryLevel = map(analogRead(36), 0, 4095, 0, 100);

  // Отправка данных
  esp_err_t result = esp_now_send(receiverMac, (uint8_t *)&txData, sizeof(txData));
  
  // Отладочная информация
  Serial.printf("J1: %d,%d BTN:%d | J2: %d,%d BTN:%d | Status: %s\n",
    txData.joy1_x, txData.joy1_y, txData.joy1_btn,
    txData.joy2_x, txData.joy2_y, txData.joy2_btn,
    result == ESP_OK ? "OK" : "FAIL");
}

void loop() {
  sendData();
  delay(SEND_DELAY);
}

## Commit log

2025-12-30 Update README with additional joystick resources
    Added links for Hall TMR joystick electrical properties and PS5 hall joysticks.
2025-12-30 Add link to thumbstick breakout board image
2026-05-07 GA install
    [supply.kicad_sch]
2026-08-01 Remove leftover PlatformIO skeleton dirs and orphaned st7789 header
    include/, lib/, test/ were unused PlatformIO scaffold placeholders, and
    components/st7789/include/st7789.h was an early, superseded draft of the
    display header never wired into the ESP-IDF build (main/st7789_display.h
    is the one actually used).
2026-08-02 shema correction. pcb is not updated
    [esp32-controller.kicad_pcb]
2026-09-07 switch to version 10
    [esp32-controller.kicad_pcb, esp32-controller.kicad_sch, supply.kicad_sch]
